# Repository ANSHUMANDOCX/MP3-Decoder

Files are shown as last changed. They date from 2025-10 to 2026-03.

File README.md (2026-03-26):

# MP3 Player

This is a Portable MP3 player which allows one to play music on the even at places where there is no internet access.
You can also view almost all the details you would require while listenting to music on the OLED dispaly that will be connected to it.
Also has a capbility to be programmed using a Arduino or a FTDI programmer.

**Untested Firmware**

Features-
- Atmega328p as a MCU
- DF player MINI (DFR0299) as a MP3 decoder(since i already had it lying around)
- 128x64 0.96 inch OLED display for UI
- Inbuilt charging using TP4056
- 4 iterfacing buttons Play/Pause  Prev/Vol-  Next/Vol+ and RESET for the board 
- Onboard leds for debugging,Power,Charging and Playing status

## Notes for V2 + last minute changes 
- The temp pin of the tp4056 ic needs to be grounded instead of being left open since it puss that pin to a random value and doesnt allow the battery to be charged
- i need to route the next and prev buttons to one of the io pins of the atmega chip since earlier i had it on the adkey mode of the df player which when pressed puts board in a where it no longer receives commands from the mcu
- one of the most obvious this i missed is adding a switch to turn off the 5v from the boost ic directly since now whenever i charge the board the board stays on permanently so to overcome that i have temporarily added button combination to put the df player to sleep.
- in the image u can see that ive added jumpers to the board for connecting the pay pause button to the mcu directly.

# PCB Schematic and CAD





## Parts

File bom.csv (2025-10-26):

Designator | Footprint | Quantity | Value | LCSC Part #
C1, C2 | 0603 | 2 | 22pf
C10 | 1206 | 1 | 100uf
C3, C4 | 0603 | 2 | 10uf
C5, C6 | 0603 | 2 | 22uf
C7, C9 | 0603 | 2 | 0.1uf
D1, D2, D4, D6 | 0603 | 4 | LED
D3 | D_SMA | 1 | SS34
FB1 | 0805 | 1 | FerriteBead_Small
J1 | USB_C_Receptacle_GCT_USB4125-xx-x_6P_TopMnt_Horizontal | 1 | USB_C_Receptacle_PowerOnly_6P
J2 | PinHeader_1x02_P2.54mm_Vertical | 1 | BAT
J3 | PinHeader_2x04_P2.54mm_Vertical | 1 | Conn_02x04_Counter_Clockwise
J4 | PinHeader_1x04_P2.54mm_Vertical | 1 | OLED
J5 | Jack_3.5mm_KoreanHropartsElec_PJ-320D-4A_Horizontal | 1 | AudioJack4
L1 | L_APV_ANR4030 | 1 | L
R1 | 0603 | 1 | 100R
R10, R11, R12, R3, R4 | 0603 | 5 | 1k
R2 | 0603 | 1 | 10k
R5 | 0603 | 1 | 1.2k
R6 | 0603 | 1 | 750k
R7, R8, R9 | 0603 | 3 | 100k
SW1 | SW_SPST_CK_RS282G05A3 | 1 | SW_Push
SW2 | SW_SPST_CK_RS282G05A3 | 1 | SW_Prev/Vol -
SW3 | SW_SPST_CK_RS282G05A3 | 1 | SW_Next/Vol+
SW4 | SW_SPST_CK_RS282G05A3 | 1 | Play/Pause
U1 | TQFP-32_7x7mm_P0.8mm | 1 | ATmega328P-A
U2 | MODULE_DFR0299 | 1 | DFR0299
U3 | SOIC-8-1EP_3.9x4.9mm_P1.27mm_EP2.41x3.3mm_ThermalVias | 1 | TP4056-42-ESOP8
U4 | SOT-23-6 | 1 | MT3608
Y2 | Crystal_SMD_5032-2Pin_5.0x3.2mm | 1 | 16 Mhz

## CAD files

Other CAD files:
CAD/Base.f3z
CAD/TOP.f3z

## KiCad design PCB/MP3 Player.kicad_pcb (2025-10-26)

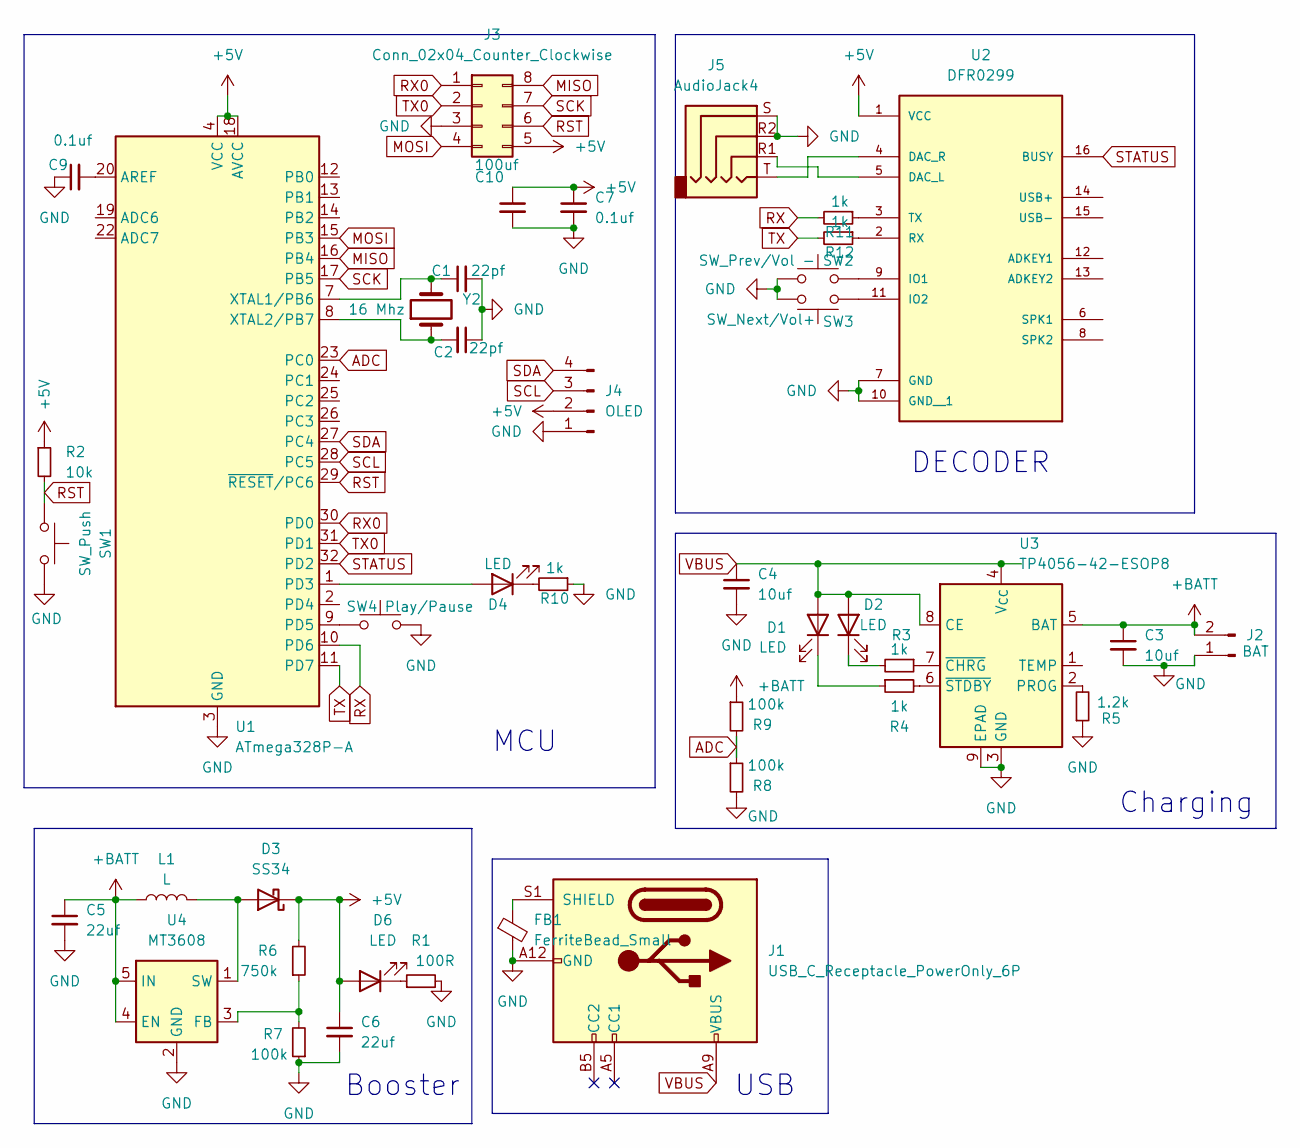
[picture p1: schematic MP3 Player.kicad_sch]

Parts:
C1, C2: 22pf; C_0603_1608Metric
C3, C4: 10uf; C_0603_1608Metric
C5, C6: 22uf; C_0603_1608Metric
C7, C9: 0.1uf; C_0603_1608Metric
C10: 100uf; C_1206_3216Metric
D1, D2, D4, D6: LED; LED_0603_1608Metric
D3: SS34; D_SMA
FB1: FerriteBead_Small; R_0805_2012Metric
J1: USB_C_Receptacle_PowerOnly_6P; USB_C_Receptacle_GCT_USB4125-xx-x_6P_TopMnt_Horizontal
J2: BAT; PinHeader_1x02_P2.54mm_Vertical
J3: Conn_02x04_Counter_Clockwise; PinHeader_2x04_P2.54mm_Vertical
J4: OLED; PinHeader_1x04_P2.54mm_Vertical
J5: AudioJack4; Jack_3.5mm_KoreanHropartsElec_PJ-320D-4A_Horizontal
L1: L; L_Bourns_SRP7028A_7.3x6.6mm
R1: 100R; R_0603_1608Metric
R2: 10k; R_0603_1608Metric
R3, R4, R10, R11, R12: 1k; R_0603_1608Metric
R5: 1.2k; R_0603_1608Metric
R6: 750k; R_0603_1608Metric
R7, R8, R9: 100k; R_0603_1608Metric
SW1: SW_Push; SW_SPST_CK_RS282G05A3
SW2: SW_Prev/Vol -; SW_SPST_CK_RS282G05A3
SW3: SW_Next/Vol+; SW_SPST_CK_RS282G05A3
SW4: Play/Pause; SW_SPST_CK_RS282G05A3
U1: ATmega328P-A; TQFP-32_7x7mm_P0.8mm
U2: DFR0299; MODULE_DFR0299
U3: TP4056-42-ESOP8; SOIC-8-1EP_3.9x4.9mm_P1.27mm_EP2.41x3.3mm_ThermalVias
U4: MT3608; SOT-23-6
Y2: 16 Mhz; Crystal_SMD_5032-2Pin_5.0x3.2mm

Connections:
+5V: C6.1, C7.1, C10.1, D3.1 (K), D6.2 (A), J3.5, J4.2, R2.1, R6.2, U1.4 (VCC), U1.6 (VCC), U1.18 (AVCC), U2.1 (VCC); also elsewhere on the board
+BATT: C3.1, C5.1, J2.2, L1.1, R9.1, U3.5 (BAT), U4.4 (EN), U4.5 (IN)
ADC: R8.1, R9.2, U1.23 (PC0)
GND: C1.2, C2.1, C3.2, C4.2, C5.2, C6.2, C7.2, C9.1, C10.2, FB1.2, J1.A12 (GND), J1.B12 (GND), J2.1, J3.3, J4.1, J5.R2, J5.S, R1.2, R5.1, R7.1, R8.2, R10.1, SW1.2, SW2.1, SW3.1, SW4.2, U1.3 (GND), U1.5 (GND), U1.21 (GND), U2.7 (GND), U2.10 (GND__1), U3.3 (GND), U3.9 (EPAD), U4.2 (GND); also elsewhere on the board
MISO: J3.8, U1.16 (PB4)
MOSI: J3.4, U1.15 (PB3)
unnamed: D1.1 (K), R4.1
unnamed: D2.1 (K), R3.2
unnamed: D3.2 (A), L1.2, U4.1 (SW)
unnamed: D4.2 (A), U1.1 (PD3)
unnamed: D4.1 (K), R10.2
unnamed: D6.1 (K), R1.1
unnamed: FB1.1, J1.S1 (SHIELD)
unnamed: C9.2, U1.20 (AREF)
unnamed: SW4.1, U1.9 (PD5)
unnamed: C1.1, U1.7 (XTAL1/PB6), Y2.2
unnamed: C2.2, U1.8 (XTAL2/PB7), Y2.1
unnamed: J5.R1, U2.5 (DAC_L)
unnamed: J5.T, U2.4 (DAC_R)
unnamed: SW2.2, U2.9 (IO1)
unnamed: SW3.2, U2.11 (IO2)
unnamed: R12.1, U2.2 (RX)
unnamed: R11.1, U2.3 (TX)
unnamed: R5.2, U3.2 (PROG)
unnamed: R3.1, U3.7 (~CHRG)
unnamed: R4.2, U3.6 (~STDBY)
unnamed: R6.1, R7.2, U4.3 (FB)
RST: J3.6, R2.2, SW1.1, U1.29 (~RESET/PC6)
RX: R11.2, U1.10 (PD6)
RX0: J3.1, U1.30 (PD0)
SCK: J3.7, U1.17 (PB5)
SCL: J4.3, U1.28 (PC5)
SDA: J4.4, U1.27 (PC4)
STATUS: U1.32 (PD2), U2.16 (BUSY)
TX: R12.2, U1.11 (PD7)
TX0: J3.2, U1.31 (PD1)
VBUS: C4.1, D1.2 (A), D2.2 (A), J1.A9 (VBUS), J1.B9 (VBUS), U3.4 (V_{CC}), U3.8 (CE)

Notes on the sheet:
Booster
Charging
MCU
DECODER
USB

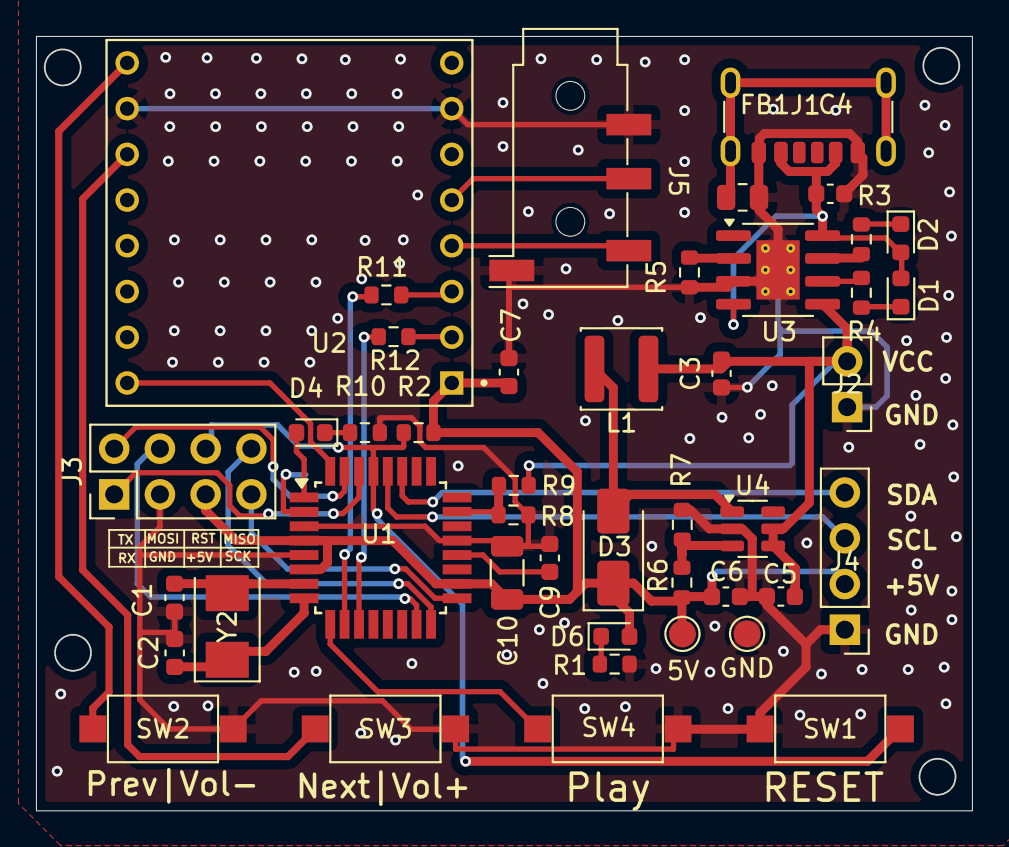
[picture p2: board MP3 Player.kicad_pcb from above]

Board: 2 copper layers, 52.0 x 43.0 mm, 45 parts (1 on the bottom side), 37 nets.

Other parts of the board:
5V: TestPoint_Pad_D1.5mm
GND: TestPoint_Pad_D1.5mm
GND#2: TestPoint_Pad_D1.0mm

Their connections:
+5V: 5V.1; also elsewhere on the board
GND: GND.1, GND#2.1; also elsewhere on the board

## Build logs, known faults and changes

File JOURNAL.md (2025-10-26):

<!--
  ===================    !!READ THIS NOTICE!!   ====================
  DO NOT edit this file manually. Your changes WILL BE OVERWRITTEN!
  This journal is auto generated and updated by Hack Club Blueprint.
  To edit this file, please edit your journal entries on Blueprint.
  ==================================================================
-->

## 10/24/2025 12 AM - Began with Reading Datasheets  

Read the Data sheet of the DF robot mp3 player and Atmega328p. Also i will be using a 3.7 LiPo battery with it so i would need to step up the voltage to 5v for the module and Atmega328p IC run properly. 
Thinking of using mt3608 step up ic.
Will also be adding a charging circuit to make it as portable as possible. 
Thinking of adding a OLED display to it for seeing the status and track playing but no sure about it since i will need to design a enclosure incase i am adding one. Also adding it will cause a significant dip in the backup time . will decide later 

https://ww1.microchip.com/downloads/en/DeviceDoc/Atmel-7810-Automotive-Microcontrollers-ATmega328P_Datasheet.pdf
https://wiki.dfrobot.com/dfplayer_mini_sku_dfr0299



## 10/24/2025 1 PM - completed the schematic   

Began with sourcing the Symbol and Footprint for the DF mini mp3 player. Took a look at existing circuits using base atmega328p. Also decided to add a ADC pin to constantly monitor the battery voltage and show the playtime left on the oled. 
visually the schematic needs some more polishing will do it later.



## 10/25/2025 12 AM - Polished the schematic and Routed the PCB  

I properly labelled the sections of the Schematic and made it look cleaner.
Started out with the PCB completed routing and turns out finding the exact package of the component u have with u in kicad is a challenge.
Spent a considerable amount of time just looking at the PCB after complete routing to find the best and the most optimized route for a trace as possible. The pcb still needs some more work more of adding graphics and test points. 




## 10/25/2025 1 PM - Completed the PCB more or less  

Added all the pin labels multiple ground vias. i also decided to add a test point for 5v since i am using a mt3608 voltage booster ic so before i assemble the rest of the components i need to check if the board a 5v constant or not so added test point for those. 
added labeled the buttons and the programing header pinwise.
this the almost final pcb 





## 10/25/2025 3 PM - started with the 3d model   

imported the DXF from kicad to exactly match the positions of the holes on the pcb since they are not uniformly placed. planning to keep 4mm borders but still not sure how i will screw them in place since the screws i have have a big head maybe will get some counter sunk ones. 
here is the sketch 

## 10/25/2025 7 PM - Made the Base of the model  

Made the rough part of the base also put in the 3d board for referencing.
planning to use heatset inserts for fixing the PCB to base. 
thinking to attach the top directly to the body since i dont want to made the walls of the case thick.




## 10/26/2025 - Completing the CAD  

Added Holes for the Switch and the charging indicator also raised the overall height to house the battery inside of it too.

Also designed the top also made proper housing for the OLED display in it.



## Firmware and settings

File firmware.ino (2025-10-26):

#include <SoftwareSerial.h>
#include <Wire.h>
#include <Adafruit_GFX.h>
#include <Adafruit_SSD1306.h>
#include <DFRobotDFPlayerMini.h>

#define RX_PIN 0   
#define TX_PIN 1  
#define PLAY_BUTTON 4
#define STATUS_LED 5
#define BATT_SENSE A0

#define SCREEN_WIDTH 128
#define SCREEN_HEIGHT 64
Adafruit_SSD1306 display(SCREEN_WIDTH, SCREEN_HEIGHT, &Wire, -1);

SoftwareSerial mp3Serial(RX_PIN, TX_PIN); 
DFRobotDFPlayerMini mp3;

bool isPlaying = false;
unsigned long lastDebounce = 0;
int lastButtonState = HIGH;


int batteryPercentage() {
  int adc = analogRead(BATT_SENSE);
  float voltage = (adc / 1023.0) * 5.0; 

  voltage *= 2.0; 
  int percent = map(voltage * 100, 330, 420, 0, 100); 
  percent = constrain(percent, 0, 100);
  return percent;
}

void setup() {
  pinMode(PLAY_BUTTON, INPUT_PULLUP);
  pinMode(STATUS_LED, OUTPUT);

  mp3Serial.begin(9600);
  Serial.begin(9600);

  if (!display.begin(SSD1306_SWITCHCAPVCC, 0x3C)) {
    while (1);
  }
  display.clearDisplay();
  display.setTextColor(SSD1306_WHITE);
  display.setTextSize(1);

  display.setCursor(0, 10);
  display.println("Initializing DFPlayer...");
  display.display();

  if (!mp3.begin(mp3Serial)) {
    display.clearDisplay();
    display.setCursor(0, 10);
    display.println("DFPlayer not found!");
    display.display();
    while (true);
  }

  mp3.volume(20);
  mp3.play(1);    
  isPlaying = true;
  digitalWrite(STATUS_LED, HIGH);
}

void loop() {
  int buttonState = digitalRead(PLAY_BUTTON);
  if (buttonState == LOW && lastButtonState == HIGH && millis() - lastDebounce > 300) {
    lastDebounce = millis();
    if (isPlaying) {
      mp3.pause();
      isPlaying = false;
      digitalWrite(STATUS_LED, LOW);
    } else {
      mp3.start();
      isPlaying = true;
      digitalWrite(STATUS_LED, HIGH);
    }
  }
  lastButtonState = buttonState;

  display.clearDisplay();
  display.setCursor(0, 0);
  display.setTextSize(1);
  display.println("MP3 Player");
  display.setTextSize(2);
  display.setCursor(0, 20);
  display.println(isPlaying ? "Playing" : "Paused");

  display.setTextSize(1);
  display.setCursor(0, 48);
  display.print("Battery: ");
  display.print(batteryPercentage());
  display.println("%");

  display.display();
  delay(300);
}
